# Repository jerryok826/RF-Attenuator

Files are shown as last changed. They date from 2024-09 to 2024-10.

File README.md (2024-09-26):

# RF Attenuator

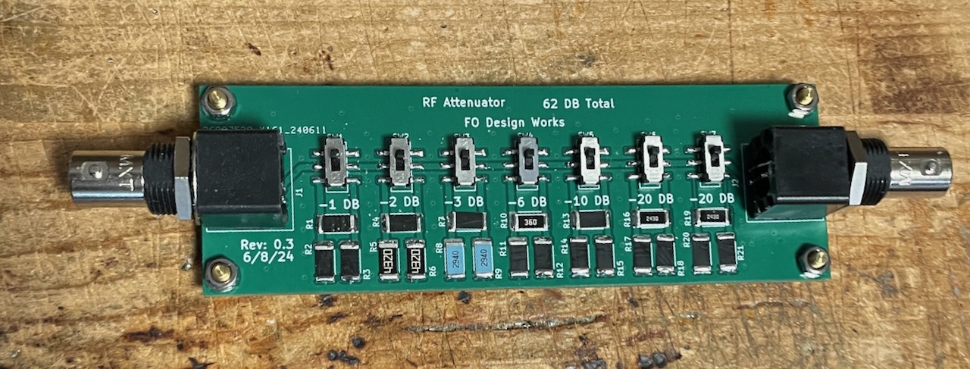
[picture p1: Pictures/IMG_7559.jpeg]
Robot_Front


## Project Description
I always liked the HP/Agilent 355 Step Attenuators. Now with Kicad and low cost PCB fabrication I thought I should just design my own. The attenuator uses BNC connector rather than SMA beause I like the quick disconnet feature. The design is base on 1 watt resistors so that the power limit. Total Attenuation is 62DB in 1 DB steps.

### Project Status
The project is complete and has be verifyed with a Rigol DSA816 spectrum analyer from 1MHz to 30MHz.

## Design Files
### Electrical Design Files
This project was designed with Kicad 7.X

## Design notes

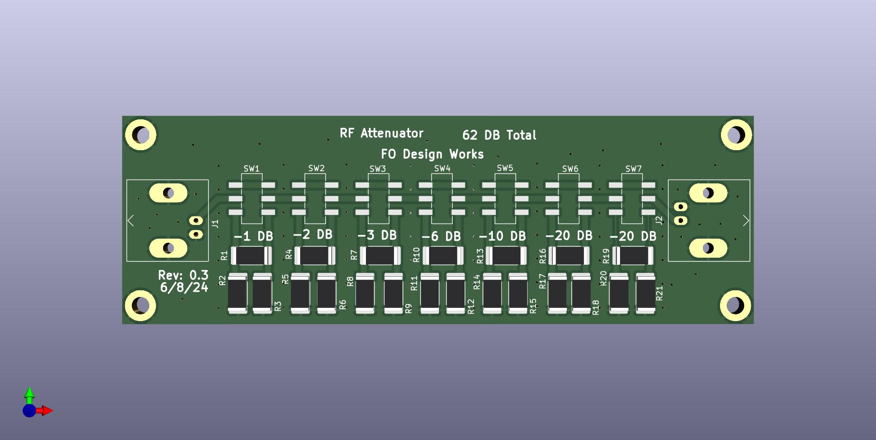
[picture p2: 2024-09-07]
Hardware/Kicad/rf_attenuator_r3.jpg

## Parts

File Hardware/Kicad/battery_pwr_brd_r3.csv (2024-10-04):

Source: | /home/jerryo/kicad/battery_pwr_brd/battery_pwr_brd_r3/battery_pwr_brd_r3.kicad_sch
Date: | Fri 04 Oct 2024 03:51:49 PM PDT
Tool: | Eeschema 7.0.11-7.0.11~ubuntu22.04.1
Generator: | /usr/share/kicad/plugins/bom_csv_grouped_by_value.py
Component Count: | 23
Collated Components:
Item | Qty | Reference(s) | Value | LibPart | Footprint | Datasheet | DNP | Description | Vendor | Vendor Part#
1 | 1 | BT1 | BATT HLD COIN 20MM 2 CELL PC PIN | Device:Battery | Battery:BatteryHolder_Keystone_103_1x20mm | ~ |  |  | Digikey | BH800S-ND
2 | 4 | C1, C2, C7, C8 | 0.1uF | Device:C_Small | Capacitor_SMD:C_0805_2012Metric_Pad1.18x1.45mm_HandSolder | ~ |  | CAP CER, 0.1uF, 25V, X7R, 0805 | Digikey | 1276-1099-1-ND
3 | 2 | C3, C6 | 4.7uF | Device:C_Small | Capacitor_SMD:C_0805_2012Metric_Pad1.18x1.45mm_HandSolder | ~ |  | CAP CER, 4.7uF, 25V, X7R, 0805 | Digikey | 1276-1244-1-ND
4 | 2 | C4, C5 | 1uF | Device:C_Small | Capacitor_SMD:C_0805_2012Metric_Pad1.18x1.45mm_HandSolder | ~ |  | CAP CER 1UF 25V X7R 0805 | Digikey | 1276-1066-1-ND
5 | 1 | D1 | PWR_OK | Device:LED | LED_SMD:LED_1206_3216Metric_Pad1.42x1.75mm_HandSolder | https://sunledusa.com/products/spec/XZM2CRK55W-3.pdf |  | LED RED CLEAR SMD 1206 | Digikey | 732-11422-1-ND
6 | 2 | D2, D4 | 1N5819W | Diode:1N5819WS | Diode_SMD:D_SOD-123 | https://datasheet.lcsc.com/lcsc/2204281430_Guangdong-Hottech-1N5819WS_C191023.pdf |  | DIODE SCHOTTKY 40V 1A SOD123FL | Digikey | 1655-1N5819WCT-ND
7 | 1 | FB1 | FerriteBead, 6A 1 9mΩ 33Ω@100MHz ±25% 1206 Ferrite Beads ROHS | Device:FerriteBead_Small | Inductor_SMD:L_1206_3216Metric_Pad1.42x1.75mm_HandSolder | https://www.fair-rite.com/wp-content/themes/fair-rite/print_product.php?pid=19229 |  | FERRITE BEAD 50 OHM 1206 1LN | Digikey | 1934-1465-1-ND
8 | 1 | J2 | Output_5V | Connector_Generic:Conn_01x02 |  | ~
9 | 1 | J3 | Output_3V3 | Connector_Generic:Conn_01x02 |  | ~
10 | 1 | Q2 | MMBT3904 | Transistor_BJT:MMBT3904 | Package_TO_SOT_SMD:SOT-23 | https://www.onsemi.com/pdf/datasheet/pzt3904-d.pdf |  | TRANS NPN 40V 0.2A SOT23-3 | Digikey | SMMBT3904LT3GOSCT-ND
11 | 1 | R1 | 100K | Device:R_Small_US | Resistor_SMD:R_0805_2012Metric_Pad1.20x1.40mm_HandSolder | ~ |  | RES 100K OHM %1 1/10W 0805 SMD | Digikey | 311-100KCRCT-ND
12 | 1 | R2 | 2.7K | Device:R_Small_US | Resistor_SMD:R_0805_2012Metric_Pad1.20x1.40mm_HandSolder | ~ |  | RES 2.7K OHM %1 1/10W 0805 SMD | Digiley | A126359CT-ND
13 | 1 | R3 | 5.1K | Device:R_Small_US | Resistor_SMD:R_0805_2012Metric_Pad1.20x1.40mm_HandSolder | ~ |  | RES 5.1K OHM %1 1/10W 0805 SMD | Digikey | 311-5.1KARCT-ND
14 | 1 | R4 | 10K | Device:R_Small_US | Resistor_SMD:R_0805_2012Metric_Pad1.20x1.40mm_HandSolder | ~ |  | RES 10K OHM %1 1/10W 1206 SMD | Digkey | 311-10.0KCRCT-ND
15 | 1 | SW1 | SW_DPDT_x2 | :SW_DPDT_x2_1 | jerrys_Library:SW_DPDT_CK_JS202011JCQN | https://www.ckswitches.com/media/1422/js.pdf |  | SWITCH SLIDE DPDT 300MA 6V | Digikey | 401-2002-1-ND
16 | 1 | U1 | MCP1755 | :MCP1755_1 | Package_TO_SOT_SMD:SOT-223-6 | https://ww1.microchip.com/downloads/en/DeviceDoc/MCP1755-MCP1755S-Data-Sheet-DS20005160B.pdf |  | IC REG LIN 3.3V 300MA SOT223-3 | Digikey | MCP1755ST-3302E/DBCT-ND
17 | 1 | U2 | LM1117MP-3.3 | Regulator_Linear:LM1117MP-3.3 | Package_TO_SOT_SMD:SOT-223-3_TabPin2 | http://www.ti.com/lit/ds/symlink/lm1117.pdf |  | IC REG LINEAR 3.3V 800MA SOT223 | Digikey | 497-1242-1-ND

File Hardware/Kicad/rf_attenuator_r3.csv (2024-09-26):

Source: | /home/jerryo/kicad/rf_attenuator/rf_attenuator_r3/rf_attenuator_r3.kicad_sch
Date: | Thu 26 Sep 2024 01:36:54 PM PDT
Tool: | Eeschema 7.0.11-7.0.11~ubuntu22.04.1
Generator: | /usr/share/kicad/plugins/bom_csv_grouped_by_value.py
Component Count: | 30
Collated Components:
Item | Qty | Reference(s) | Value | LibPart | Footprint | Datasheet | DNP | Vendor | Vendor Part#
1 | 2 | J1, J2 | BNC | Connector:Conn_Coaxial | Connector_Coaxial:BNC_Amphenol_B6252HB-NPP3G-50_Horizontal | ~ |  | Digikey | WM5514-ND
2 | 1 | R1 | 5.9 | Device:R_US | Resistor_SMD:R_2512_6332Metric_Pad1.40x3.35mm_HandSolder | ~ |  | Digikey | 541-5.90RCT-ND
3 | 2 | R2, R3 | 866 | Device:R_US | Resistor_SMD:R_2512_6332Metric_Pad1.40x3.35mm_HandSolder | ~ |  | Digikey | 541-866AFCT-ND
4 | 1 | R4 | 11.5 | Device:R_US | Resistor_SMD:R_2512_6332Metric_Pad1.40x3.35mm_HandSolder | ~ |  | Digikey | 541-11.5AFCT-ND
5 | 2 | R5, R6 | 432 | Device:R_US | Resistor_SMD:R_2512_6332Metric_Pad1.40x3.35mm_HandSolder | ~ |  | Digikey | 118-CR2512-FX-4320ELFCT-ND
6 | 1 | R7 | 17.8 | Device:R_US | Resistor_SMD:R_2512_6332Metric_Pad1.40x3.35mm_HandSolder | ~ |  | Digikey | 541-17.8AFCT-ND
7 | 2 | R8, R9 | 294 | Device:R_US | Resistor_SMD:R_2512_6332Metric_Pad1.40x3.35mm_HandSolder | ~ |  | Digikey | 2019-RK73H3ATTE2940FCT-ND
8 | 1 | R10 | 36 | Device:R_US | Resistor_SMD:R_2512_6332Metric_Pad1.40x3.35mm_HandSolder | ~ |  | Digikey | RMCF2512JT36R0CT-ND
9 | 2 | R11, R12 | 150 | Device:R_US | Resistor_SMD:R_2512_6332Metric_Pad1.40x3.35mm_HandSolder | ~ |  | Digikey | 541-150AFCT-ND
10 | 1 | R13 | 71.5 | Device:R_US | Resistor_SMD:R_2512_6332Metric_Pad1.40x3.35mm_HandSolder | ~ |  | Digikey | 541-71.5AFCT-ND
11 | 2 | R14, R15 | 95.3 | Device:R_US | Resistor_SMD:R_2512_6332Metric_Pad1.40x3.35mm_HandSolder | ~ |  | Digikey | 541-95.3AFCT-ND
12 | 2 | R16, R19 | 243 | Device:R_US | Resistor_SMD:R_2512_6332Metric_Pad1.40x3.35mm_HandSolder | ~ |  | Digikey | RMCF2512FT243RCT-ND
13 | 4 | R17, R18, R20, R21 | 61.9 | Device:R_US | Resistor_SMD:R_2512_6332Metric_Pad1.40x3.35mm_HandSolder | ~ |  | Digikey | 541-61.9AFCT-ND
14 | 7 | SW1, SW2, SW3, SW4, SW5, SW6, SW7 | SW_DPDT_x2 | Switch:SW_DPDT_x2 | jerrys_Library:SW_DPDT_CK_JS202011JCQN | ~ |  | Digikey | 401-2002-1-ND

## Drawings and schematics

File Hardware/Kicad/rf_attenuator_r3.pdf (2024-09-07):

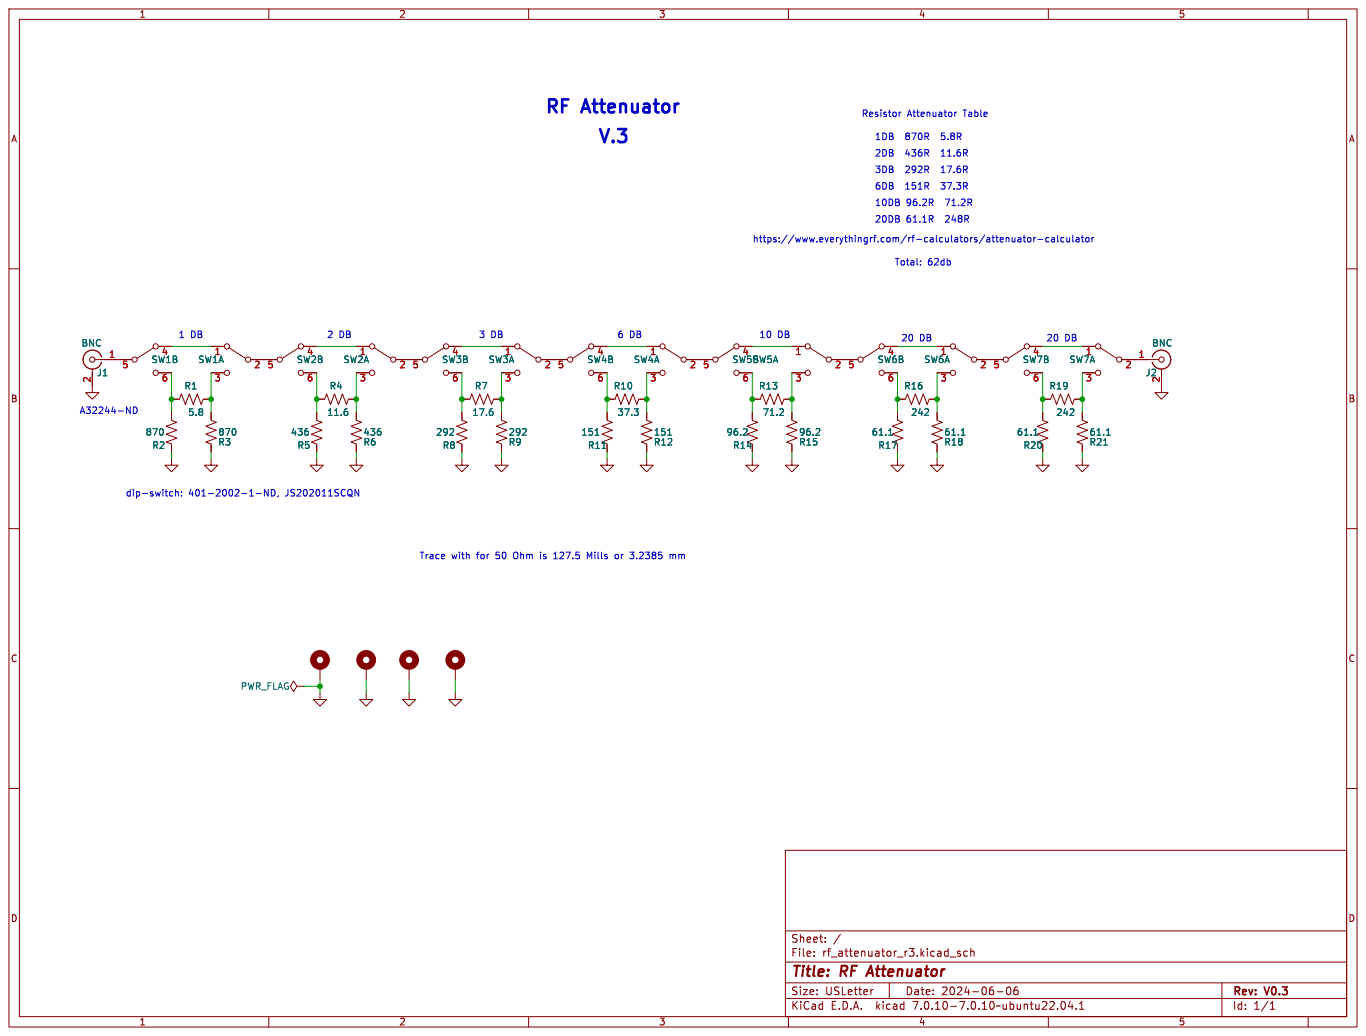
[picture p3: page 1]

Id: 1/1 Title: RF Attenuator File: rf_attenuator_r3.kicad_sch Sheet: /

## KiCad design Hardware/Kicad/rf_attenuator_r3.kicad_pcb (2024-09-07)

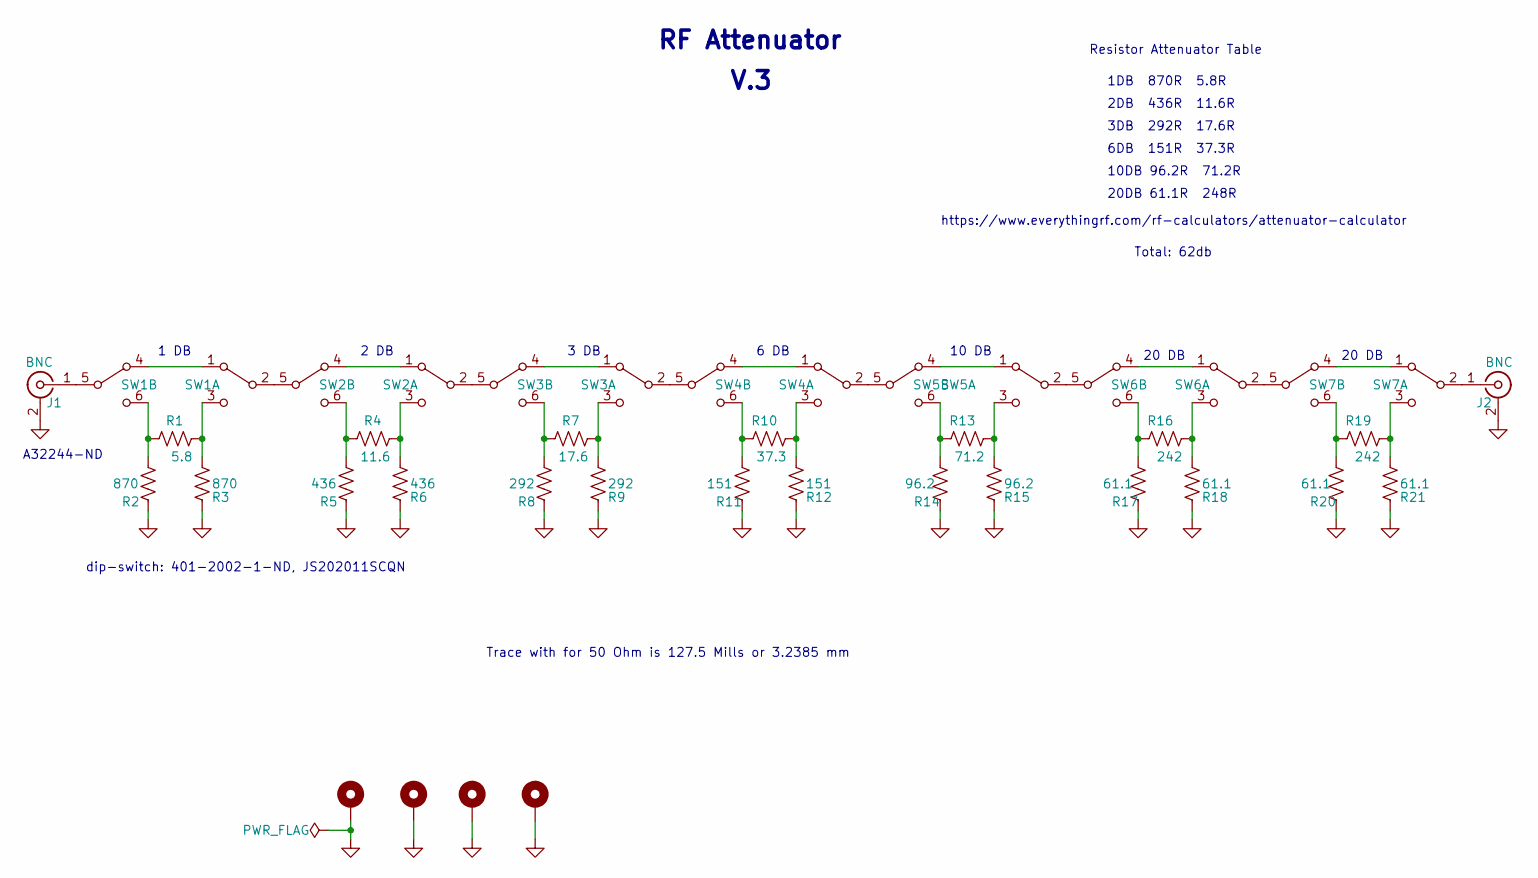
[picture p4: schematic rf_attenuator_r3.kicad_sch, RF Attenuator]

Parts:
H1, H2, H3, H4: MountingHole_Pad; MountingHole_3.2mm_M3_ISO7380_Pad_TopBottom
J1, J2: BNC; BNC_Amphenol_B6252HB-NPP3G-50_Horizontal
R1: 5.8; R_2512_6332Metric_Pad1.40x3.35mm_HandSolder
R2, R3: 870; R_2512_6332Metric_Pad1.40x3.35mm_HandSolder
R4: 11.6; R_2512_6332Metric_Pad1.40x3.35mm_HandSolder
R5, R6: 436; R_2512_6332Metric_Pad1.40x3.35mm_HandSolder
R7: 17.6; R_2512_6332Metric_Pad1.40x3.35mm_HandSolder
R8, R9: 292; R_2512_6332Metric_Pad1.40x3.35mm_HandSolder
R10: 37.3; R_2512_6332Metric_Pad1.40x3.35mm_HandSolder
R11, R12: 151; R_2512_6332Metric_Pad1.40x3.35mm_HandSolder
R13: 71.2; R_2512_6332Metric_Pad1.40x3.35mm_HandSolder
R14, R15: 96.2; R_2512_6332Metric_Pad1.40x3.35mm_HandSolder
R16, R19: 242; R_2512_6332Metric_Pad1.40x3.35mm_HandSolder
R17, R18, R20, R21: 61.1; R_2512_6332Metric_Pad1.40x3.35mm_HandSolder
SW1, SW2, SW3, SW4, SW5, SW6, SW7: SW_DPDT_x2; SW_DPDT_CK_JS202011JCQN

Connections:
GND: H1.1, H2.1, H3.1, H4.1, J1.2 (Ext), J2.2 (Ext), R2.2, R3.2, R5.2, R6.2, R8.2, R9.2, R11.2, R12.2, R14.2, R15.2, R17.2, R18.2, R20.2, R21.2
unnamed: J1.1 (In), SW1.5 (B)
unnamed: J2.1 (In), SW7.2 (B)
unnamed: SW1.1 (A), SW1.4 (A)
unnamed: SW1.2 (B), SW2.5 (B)
unnamed: R1.2, R3.1, SW1.3 (C)
unnamed: R1.1, R2.1, SW1.6 (C)
unnamed: SW2.1 (A), SW2.4 (A)
unnamed: SW2.2 (B), SW3.5 (B)
unnamed: R4.2, R6.1, SW2.3 (C)
unnamed: R4.1, R5.1, SW2.6 (C)
unnamed: SW3.1 (A), SW3.4 (A)
unnamed: SW3.2 (B), SW4.5 (B)
unnamed: R7.2, R9.1, SW3.3 (C)
unnamed: R7.1, R8.1, SW3.6 (C)
unnamed: SW4.1 (A), SW4.4 (A)
unnamed: SW4.2 (B), SW5.5 (B)
unnamed: R10.2, R12.1, SW4.3 (C)
unnamed: R10.1, R11.1, SW4.6 (C)
unnamed: SW5.1 (A), SW5.4 (A)
unnamed: SW5.2 (B), SW6.5 (B)
unnamed: R13.2, R15.1, SW5.3 (C)
unnamed: R13.1, R14.1, SW5.6 (C)
unnamed: SW6.1 (A), SW6.4 (A)
unnamed: SW6.2 (B), SW7.5 (B)
unnamed: R16.2, R18.1, SW6.3 (C)
unnamed: R16.1, R17.1, SW6.6 (C)
unnamed: SW7.1 (A), SW7.4 (A)
unnamed: R19.2, R21.1, SW7.3 (C)
unnamed: R19.1, R20.1, SW7.6 (C)

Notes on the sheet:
6 DB
dip-switch: 401-2002-1-ND, JS202011SCQN
3DB 292R 17.6R
10DB 96.2R 71.2R
V.3
2 DB
https://www.everythingrf.com/rf-calculators/attenuator-calculator
RF Attenuator
6DB 151R 37.3R
Trace with for 50 Ohm is 127.5 Mills or 3.2385 mm
20 DB
20DB 61.1R 248R
10 DB
A32244-ND
Total: 62db
1 DB
1DB 870R 5.8R
Resistor Attenuator Table
2DB 436R 11.6R
3 DB

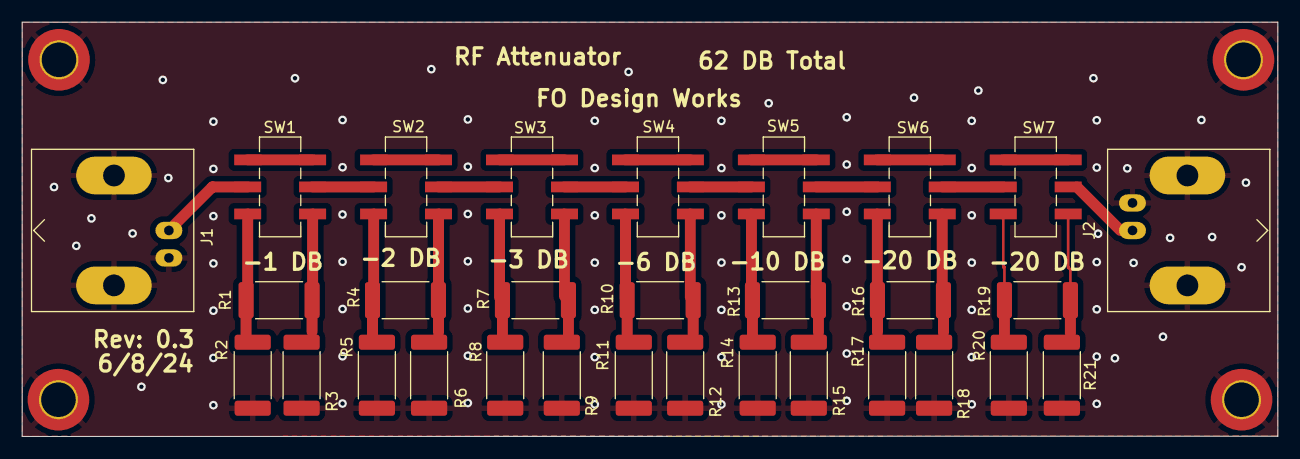
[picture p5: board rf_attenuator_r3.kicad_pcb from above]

Board: 2 copper layers, 116.1 x 38.3 mm, 34 parts (0 on the bottom side), 30 nets.
